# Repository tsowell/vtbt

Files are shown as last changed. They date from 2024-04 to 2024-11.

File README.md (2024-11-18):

# Bluetooth to LK201 bridge for DEC video terminals

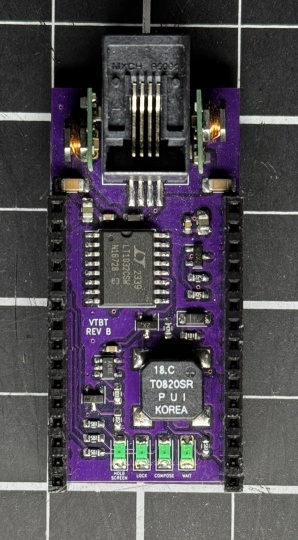
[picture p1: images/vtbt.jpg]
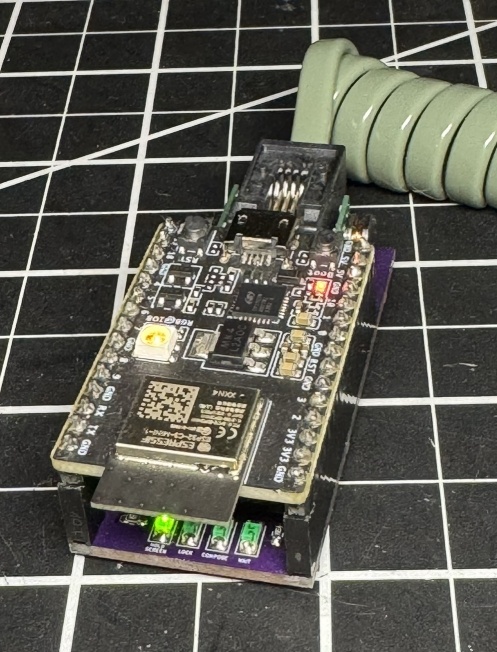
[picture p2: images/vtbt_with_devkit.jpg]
 

This repository contains Zephyr RTOS firmware code and KiCad hardware files for
a device which interfaces a DEC VT to a Bluetooth keyboard via an emulated
LK201 interface.

The vtbt board has a socket for an ESP32-C3-DevKitM-1 which provides the
microcontroller and Bluetooth functionality (as well as 3.3V regulation). The
vtbt provides power from the keyboard interface's 12V supply, performs RS-423
level conversion for the serial interface and has the four LEDs and magnetic
buzzer found in a real LK201 because Bluetooth keyboards are unlikely to have
those.

I built this after I spent great effort to obtain a VT420 but then neglected to
use it due to frustrations with the infamous LK401 keyboard. Once I got the
vtbt capable of "self-hosting", I used it with my VT420 to finish developing
the firmware over a serial console. I found that the terminal actually provides
a very enjoyable and relaxing experience with a decent keyboard!

## What works

Everything documented in the VCB02 Video Subsystem Technical manual is
implemented including:

* Beeps, keyclicks, beep and keyclick volumes
* The four LK201 LED indicators
* Per-key-division auto-repeat, up-down, down-only modes
* All mode-setting operations for changing modes and auto-repeat timings

## What doesn't work

I've only tested the vtbt with DEC VT420 terminals.

The key mapping is set up for the VT420's default "<> Key Sends `~" and "`~ Key
Sends ESC" settings. It may need adjustment for other terminals or
configurations.

Similarly, Alt keys, which are disabled by default on the VT420, are not
supported, but support could be added.

Compose keys have not been tested.

## Usage

1. Build and flash the firmware to an ESP32-C3-DevKitM-1 connected over USB.

   From a Zephyr environment:

   ```west flash```

2. Mount the ESP32-C3-DevKitM-1 on the vtbt with the USB port facing the vtbt's
   modular connector and the ESP32-C3 and antenna on the side with the LEDs.

3. Connect the vtbt to a DEC terminal with a rollover-wired 4P4C module cable
   (like a phone handset cable).

4. Turn on the DEC terminal. The vtbt will display the terminal's power-up
   self-test sequence on its four LEDs followed by a beep.

5. Connect to a Bluetooth keyboard.

   The firmware indicates Bluetooth status via the ESP32-C3-DevKitM-1's RGB
   LED.
  
   Blue means it is searching for a Bluetooth keyboard.
  
   Green means it has found a keyboard and is awaiting authorization. To
   authorize, type 123456<Enter> on the keyboard.
  
   Orange means it is connected to a keyboard and processing keyboard events.
  
   The firmware stores bonded devices and automatically reconnects to them.

## Development

The vtbt's modular connector blocks the ESP32-C3-DevKitM-1's USB port, but for
quicker iterations a pair of pin headers as spacers will make it taller.

vtemu.py in this repository can be used as a basic emulation of a DEC terminal
for testing.

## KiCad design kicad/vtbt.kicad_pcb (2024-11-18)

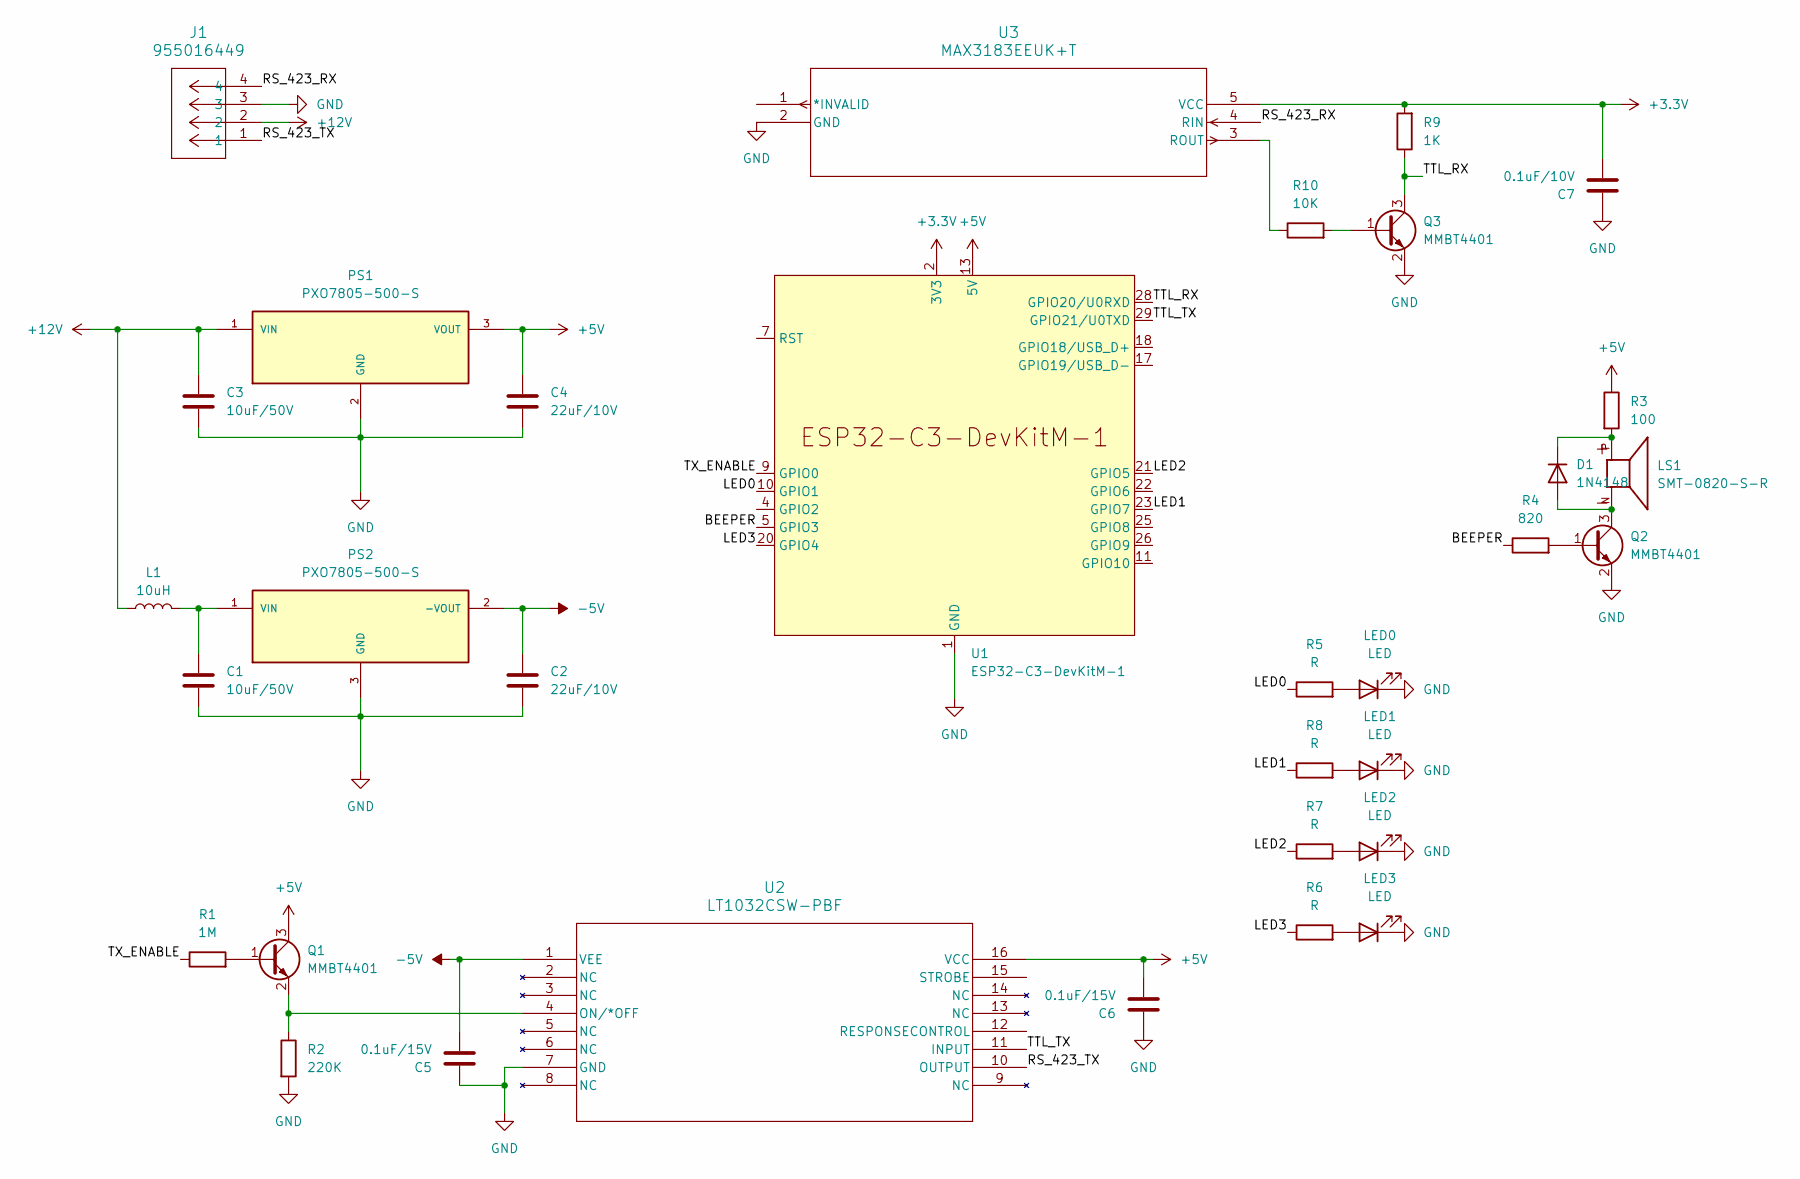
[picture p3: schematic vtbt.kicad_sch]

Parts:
C1, C3: 10uF/50V; C_1206_3216Metric_Pad1.33x1.80mm_HandSolder
C2, C4: 22uF/10V; C_0805_2012Metric_Pad1.18x1.45mm_HandSolder
C5, C6: 0.1uF/15V; C_0603_1608Metric
C7: 0.1uF/10V; C_0603_1608Metric
D1: 1N4148; D_SOD-123
J1: 955016449; CONN_95501-6449_MOL
L1: 10uH; L_0603_1608Metric_Pad1.05x0.95mm_HandSolder
LED0, LED1, LED2, LED3: LED; LED_1206_3216Metric_Pad1.42x1.75mm_HandSolder
LS1: SMT-0820-S-R; XDCR_SMT-0820-S-R; PARTREV B
PS1, PS2: PXO7805-500-S; CONV_PXO7805-500-S; PARTREV 08/22/2022
Q1, Q2, Q3: MMBT4401; SOT-23
R1: 1M; R_0603_1608Metric_Pad0.98x0.95mm_HandSolder
R2: 220K; R_0603_1608Metric_Pad0.98x0.95mm_HandSolder
R3: 100; R_0603_1608Metric_Pad0.98x0.95mm_HandSolder
R4: 820; R_0603_1608Metric_Pad0.98x0.95mm_HandSolder
R5, R6, R7, R8: R; R_0603_1608Metric_Pad0.98x0.95mm_HandSolder
R9: 1K; R_0603_1608Metric_Pad0.98x0.95mm_HandSolder
R10: 10K; R_0603_1608Metric_Pad0.98x0.95mm_HandSolder
U1: ESP32-C3-DevKitM-1; ESP32-C3-DevKitM-1_minimal
U2: LT1032CSW-PBF; SOIC-16W_7.5x10.3mm_P1.27mm
U3: MAX3183EEUK+T; SOT-23-5

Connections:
+3.3V: C7.2, R9.2, U1.2 (3V3), U1.3 (3V3), U3.5 (VCC)
+5V: C4.1, C6.2, PS1.3 (VOUT), Q1.3 (C), R3.1, U1.13 (5V), U1.14 (5V), U2.16 (VCC)
+12V: C3.1, J1.2, L1.1, PS1.1 (VIN)
-5V: C2.1, C5.2, PS2.2 (-VOUT), U2.1 (VEE)
/BEEPER: R4.1, U1.5 (GPIO3)
/LED0: R5.1, U1.10 (GPIO1)
/LED1: R8.1, U1.23 (GPIO7)
/LED2: R7.1, U1.21 (GPIO5)
/LED3: R6.1, U1.20 (GPIO4)
/RS_423_RX: J1.4, U3.4 (RIN)
/RS_423_TX: J1.1, U2.10 (OUTPUT)
/TTL_RX: Q3.3 (C), R9.1, U1.28 (GPIO20/U0RXD)
/TTL_TX: U1.29 (GPIO21/U0TXD), U2.11 (INPUT)
/TX_ENABLE: R1.1, U1.9 (GPIO0)
GND: C1.2, C2.2, C3.2, C4.2, C5.1, C6.1, C7.1, J1.3, LED0.1 (K), LED1.1 (K), LED2.1 (K), LED3.1 (K), PS1.2 (GND), PS2.3 (GND), Q2.2 (E), Q3.2 (E), R2.2, U1.1 (GND), U1.6 (GND), U1.8 (GND), U1.12 (GND), U1.15 (GND), U1.16 (GND), U1.19 (GND), U1.24 (GND), U1.27 (GND), U1.30 (GND), U2.7 (GND), U3.2 (GND)
unnamed: D1.2 (A), LS1.N, Q2.3 (C)
unnamed: D1.1 (K), LS1.P, R3.2
unnamed: LED0.2 (A), R5.2
unnamed: LED1.2 (A), R8.2
unnamed: LED2.2 (A), R7.2
unnamed: LED3.2 (A), R6.2
unnamed: C1.1, L1.2, PS2.1 (VIN)
unnamed: Q1.1 (B), R1.2
unnamed: Q1.2 (E), R2.1, U2.4 (ON/*OFF)
unnamed: Q2.1 (B), R4.2
unnamed: Q3.1 (B), R10.2
unnamed: R10.1, U3.3 (ROUT)

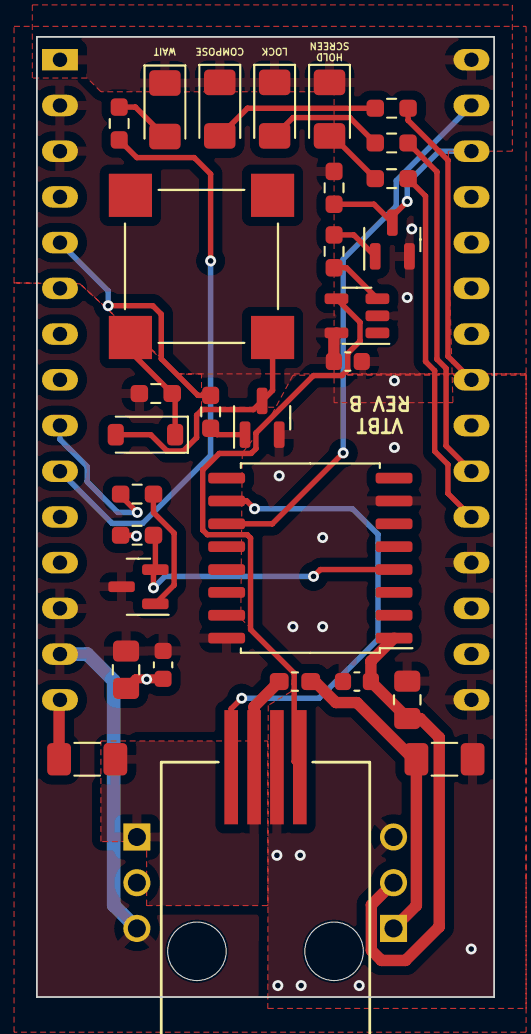
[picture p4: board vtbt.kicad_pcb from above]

Board: 2 copper layers, 25.4 x 53.3 mm, 33 parts (0 on the bottom side), 27 nets.

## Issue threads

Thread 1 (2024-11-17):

Thanks for doing this

TheWanderer1983, 2024-11-17:
I have a Dec VT420 and I'm wanting to use it with a mechanical keyboard. You have saved me a lot of time.

Regards
Dylan

TheWanderer1983, 2024-11-18:
Btw, i have a vt220 also. Did you want me to test with that?

tsowell, 2024-11-19:
That's great to hear. I've been using mine a lot lately and am super happy with it. I'd love to know how it turns out for you.

By the way, I just committed the changes for revision B of the board. The major change is that it uses rollover wiring for the modular connector, so you can use a standard phone headset cable to connect it to the terminal.

TheWanderer1983, 2024-11-24:
Any chance you could put out a gerber and bom? my kicad is stuck at an older version than the one you used.

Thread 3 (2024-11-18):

Support for USBHost

TheWanderer1983, 2024-11-18:
Hello again,

I noticed that you are using the ESP32-C3-DevKitM-1. It has support for the usbhost. See an example https://hackaday.com/2024/11/17/esp32-hosts-a-usb-keyboard-in-this-typewriter/
and
https://github.com/tanakamasayuki/EspUsbHost

Any chance you could incorporate that into this unit. Therefore being able to use a wired usb keyboard not just bluetooth.

Regards
Dylan

tsowell, 2024-11-19:
I agree that would be nice - most of my keyboards are wired, after all. I may get it to it some day, but for now I don't have a specific need for it.

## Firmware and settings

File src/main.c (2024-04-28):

#include <string.h>

#include <zephyr/kernel.h>
#include <zephyr/drivers/gpio.h>
#include <zephyr/drivers/uart.h>
#include <zephyr/logging/log.h>
#include <zephyr/drivers/pwm.h>
#include <zephyr/sys/dlist.h>

#include "vtbt.h"
#include "lk201.h"
#include "beeper.h"
#include "bluetooth.h"
#include "leds.h"
#include "metronome.h"
#include "uart.h"
#include "keyboard.h"

LOG_MODULE_REGISTER(vtbt, CONFIG_LOG_DEFAULT_LEVEL);

static bool test_mode = false;

static sys_dlist_t keys_down;

K_MSGQ_DEFINE(msgq, sizeof(struct event), 32, 4);

static struct event metronome_evt = { EVT_METRONOME, 0 , { 0 } };

static void
metronome(struct k_timer *timer_id)
{
	ARG_UNUSED(timer_id);

	k_msgq_put(&msgq, &metronome_evt, K_NO_WAIT);
}

K_TIMER_DEFINE(metronome_timer, metronome, NULL);

static struct event hid_evt = { EVT_KEYBOARD, HID_REPORT_SIZE, { 0 } };

static void
hid_report_cb(const uint8_t *hid_report)
{
	memcpy(hid_evt.buf, hid_report, HID_REPORT_SIZE);
	k_msgq_put(&msgq, &hid_evt, K_NO_WAIT);
}

static void
send_power_on_test_result(void) {
	const unsigned char test_result[] = {
		SPECIAL_KEYBOARD_ID_FIRMWARE,
		SPECIAL_KEYBOARD_ID_HARDWARE,
		0x00, /* ERROR */
		0x00, /* KEYCODE */
	};
	uart_write(test_result, sizeof(test_result));
}

static struct event callback_evt = { EVT_HOST, 0 , { 0 } };

static void
uart_callback(uint8_t c)
{
	if (c & 0x80) {
		/* no more parameters */
		callback_evt.buf[callback_evt.size++] = c;
		k_msgq_put(&msgq, &callback_evt, K_NO_WAIT);
		callback_evt.size = 0;
	} else if (callback_evt.size < 3) {
		callback_evt.buf[callback_evt.size++] = c;
	}
}

static void
init_defaults(void)
{
	test_mode = false;
	lk201_init_defaults();
	keyboard_init_defaults();
	beeper_set_keyclick_volume(2);
	beeper_set_bell_volume(2);
}

/* FLOW CONTROL */

static void
inhibit_keyboard_transmission(const struct event *event)
{
	ARG_UNUSED(event);

	leds_on(LED_LOCK);

	uart_write_byte(SPECIAL_KBD_LOCKED_ACK);
	uart_flush();
	uart_lock();
}

#define SYS_DLIST_PEEK_TAIL_CONTAINER(__dl, __cn, __n) \
	SYS_DLIST_CONTAINER(sys_dlist_peek_tail(__dl), __cn, __n)

#define SYS_DLIST_PEEK_PREV_CONTAINER(__dl, __cn, __n) \
	((__cn != NULL) ? \
	 SYS_DLIST_CONTAINER(sys_dlist_peek_prev(__dl, &(__cn->__n)),   \
	                              __cn, __n) : NULL)

#define SYS_DLIST_FOR_EACH_CONTAINER_REVERSE(__dl, __cn, __n)           \
	for (__cn = SYS_DLIST_PEEK_TAIL_CONTAINER(__dl, __cn, __n);     \
	     __cn != NULL;                                              \
	     __cn = SYS_DLIST_PEEK_PREV_CONTAINER(__dl, __cn, __n))

static void
resume_keyboard_transmission(const struct event *event)
{
	ARG_UNUSED(event);

	leds_off(LED_LOCK);

	uart_unlock();
	if (uart_overflow_get()) {
		uart_write_byte(SPECIAL_OUTPUT_ERROR);
	}

	/* Send unsent key down in reverse order */
	struct key_down *cn;
	SYS_DLIST_FOR_EACH_CONTAINER_REVERSE(&keys_down, cn, node) {
		if (cn->sent) {
			continue;
		}

		uart_write_byte(cn->keycode);
		cn->sent = true;
	}

	metronome_resend();
}

/* INDICATORS */

static void
light_leds(const struct event *event)
{
	if (event->size != 2) {
		uart_write_byte(SPECIAL_INPUT_ERROR);
		metronome_resend();
		return;
	}

	for (int i = 0; i < 4; i++) {
		if (event->buf[1] & (1 << i)) {
			leds_on(i);
		}
	}
}

static void
turn_off_leds(const struct event *event)
{
	if (event->size != 2) {
		uart_write_byte(SPECIAL_INPUT_ERROR);
		metronome_resend();
		return;
	}

	for (int i = 0; i < 4; i++) {
		if (event->buf[1] & (1 << i)) {
			leds_off(i);
		}
	}
}

/* AUDIO */

static void
disable_keyclick(const struct event *event)
{
	ARG_UNUSED(event);

	beeper_set_keyclick_volume(-1);
}

static void
enable_keyclick_set_volume(const struct event *event)
{
	if (event->size != 2) {
		uart_write_byte(SPECIAL_INPUT_ERROR);
		metronome_resend();
		return;
	}

	beeper_set_keyclick_volume(event->buf[1] & 0x07);
}

static void
disable_ctrl_keyclick(const struct event *event)
{
	ARG_UNUSED(event);

	keyboard_ctrl_keyclick_disable();
}

static void
enable_ctrl_keyclick(const struct event *event)
{
	ARG_UNUSED(event);

	keyboard_ctrl_keyclick_enable();
}

static void
sound_keyclick(const struct event *event)
{
	ARG_UNUSED(event);

	beeper_sound_keyclick();
}

static void
disable_bell(const struct event *event)
{
	ARG_UNUSED(event);

	beeper_set_bell_volume(-1);
}

static void
enable_bell_set_volume(const struct event *event)
{
	if (event->size != 2) {
		uart_write_byte(SPECIAL_INPUT_ERROR);
		metronome_resend();
		return;
	}

	beeper_set_bell_volume(event->buf[1] & 0x07);
}

static void
sound_bell(const struct event *event)
{
	ARG_UNUSED(event);

	beeper_sound_bell();
}

/* AUTO-REPEAT */

static void
temporary_auto_repeat_inhibit(const struct event *event)
{
	ARG_UNUSED(event);

	struct key_down *cn;
	SYS_DLIST_FOR_EACH_CONTAINER(&keys_down, cn, node) {
		struct division *division =
			lk201_division_get_from_keycode(cn->keycode);
		if (division == NULL) {
			continue;
		} else if (cn->inhibit_auto_repeat == true) {
			continue;
		} else if (division->mode == MODE_AUTO_REPEAT) {
			cn->inhibit_auto_repeat = true;
			break;
		}
	}
}

static void
enable_auto_repeat_across_keyboard(const struct event *event)
{
	ARG_UNUSED(event);

	metronome_auto_repeat_enable();
}

static void
disable_auto_repeat_across_keyboard(const struct event *event)
{
	ARG_UNUSED(event);

	metronome_auto_repeat_disable();
}

static void
change_all_auto_repeat_to_down_only(const struct event *event)
{
	ARG_UNUSED(event);

	lk201_change_all_auto_repeat_to_down_only();
}

/* OTHER */

static void
request_keyboard_id(const struct event *event)
{
	ARG_UNUSED(event);

	const unsigned char keyboard_id[] = {
		SPECIAL_KEYBOARD_ID_FIRMWARE,
		SPECIAL_KEYBOARD_ID_HARDWARE,
	};
	uart_write(keyboard_id, sizeof(keyboard_id));
}

static void
jump_to_power_up(const struct event *event)
{
	ARG_UNUSED(event);

	init_defaults();
	send_power_on_test_result();
}

static void
jump_to_test_mode(const struct event *event)
{
	ARG_UNUSED(event);

	test_mode = true;

	uart_write_byte(SPECIAL_TEST_MODE_ACK);
}

static void
reinstate_defaults(const struct event *event)
{
	ARG_UNUSED(event);

	init_defaults();
}

static void
test_mode_jump_to_power_up(const struct event *event)
{
	ARG_UNUSED(event);

	init_defaults();
	send_power_on_test_result();
}

static void
peripheral_command(const struct event *event)
{
	switch (event->buf[0]) {
		/* FLOW CONTROL */
		case COMMAND_RESUME_KEYBOARD_TRANSMISSION:
			resume_keyboard_transmission(event);
			break;
		case COMMAND_INHIBIT_KEYBOARD_TRANSMISSION:
			inhibit_keyboard_transmission(event);
			break;
		/* INDICATORS */
		case COMMAND_TURN_OFF_LEDS:
			turn_off_leds(event);
			break;
		case COMMAND_LIGHT_LEDS:
			light_leds(event);
			break;
		/* AUDIO */
		case COMMAND_DISABLE_KEYCLICK:
			disable_keyclick(event);
			break;
		case COMMAND_ENABLE_KEYCLICK_SET_VOLUME:
			enable_keyclick_set_volume(event);
			break;
		case COMMAND_DISABLE_CTRL_KEYCLICK:
			disable_ctrl_keyclick(event);
			break;
		case COMMAND_ENABLE_CTRL_KEYCLICK:
			enable_ctrl_keyclick(event);
			break;
		case COMMAND_SOUND_KEYCLICK:
			sound_keyclick(event);
			break;
		case COMMAND_DISABLE_BELL:
			disable_bell(event);
			break;
		case COMMAND_ENABLE_BELL_SET_VOLUME:
			enable_bell_set_volume(event);
			break;
		case COMMAND_SOUND_BELL:
			sound_bell(event);
			break;
		/* AUTO-REPEAT */
		case COMMAND_TEMPORARY_AUTO_REPEAT_INHIBIT:
			temporary_auto_repeat_inhibit(event);
			break;
		case COMMAND_ENABLE_AUTO_REPEAT_ACROSS_KEYBOARD:
			enable_auto_repeat_across_keyboard(event);
			break;
		case COMMAND_DISABLE_AUTO_REPEAT_ACROSS_KEYBOARD:
			disable_auto_repeat_across_keyboard(event);
			break;
		case COMMAND_CHANGE_ALL_AUTO_REPEAT_TO_DOWN_ONLY:
			change_all_auto_repeat_to_down_only(event);
			break;
		/* OTHER */
		case COMMAND_REQUEST_KEYBOARD_ID:
			request_keyboard_id(event);
			break;
		case COMMAND_JUMP_TO_POWER_UP:
			jump_to_power_up(event);
			break;
		case COMMAND_JUMP_TO_TEST_MODE:
			jump_to_test_mode(event);
			break;
		case COMMAND_REINSTATE_DEFAULTS:
			reinstate_defaults(event);
			break;
		default:
			uart_write_byte(SPECIAL_INPUT_ERROR);
			break;
	}
}

static void
transmission_command(const struct event *event)
{
	int division = (event->buf[0] >> 3) & 0x0f;
	if (division == 0x0f) {
		if (event->size != 3) {
			uart_write_byte(SPECIAL_INPUT_ERROR);
			metronome_resend();
			return;
		}
		int buffer = (event->buf[0] >> 1) & 0x03;
		int timeout = ((event->buf[1]) & 0x7f) * 5;
		int interval = 1000 / ((event->buf[2]) & 0x7f);
		lk201_repeat_buffer_get(buffer)->timeout = timeout;
		lk201_repeat_buffer_get(buffer)->interval = interval;
	} else if (division == 0x00) {
		uart_write_byte(SPECIAL_INPUT_ERROR);
		metronome_resend();
		return;
	} else {
		int mode = ((event->buf[0]) >> 1) & 0x03;
		lk201_division_get(division-1)->mode = mode;
		if (mode == MODE_AUTO_REPEAT) {
			if (event->size == 2) {
				int buffer = event->buf[1] & 0x7f;
				lk201_division_get(division-1)->buffer = buffer;
			} else {
				/* Default buffer? */
				lk201_division_get(division-1)->buffer = 0;
			}
		}

		uart_write_byte(SPECIAL_MODE_CHANGE_ACK);
		metronome_resend();
	}
}

static void
host_event(const struct event *event)
{
	if (event->size == 0) {
		return;
	}

	if (test_mode) {
		if (event->buf[0] == TEST_MODE_COMMAND_JUMP_TO_POWER_UP) {
			test_mode_jump_to_power_up(event);
		}
	} else {
		if (event->buf[0] & 0x01) {
			peripheral_command(event);
		} else {
			transmission_command(event);
		}
	}
}

static void
handle_events(void)
{
	struct event event;

	while (k_msgq_get(&msgq, &event, K_FOREVER) == 0) {
		switch (event.source) {
			case EVT_HOST:
				host_event(&event);
				break;
			case EVT_METRONOME:
				metronome_event(&keys_down, &event);
				break;
			case EVT_KEYBOARD:
				keyboard_event(&keys_down, &event);
				break;
			default:
				break;
		}
	}
}

int
main(void)
{
	int ret;

	sys_dlist_init(&keys_down);

	init_defaults();

	leds_init();
	beeper_init();

	for (int i = 0; i < NUM_REPEAT_BUFFERS; i++) {
		lk201_repeat_buffer_get(i)->timeout = 300;
		lk201_repeat_buffer_get(i)->interval = 30;
	}

	ret = uart_init();
	if (ret < 0) {
		LOG_ERR("UART init failed: %d", ret);
		return -1;
	}

	ret = uart_set_rx_callback(uart_callback);
	if (ret < 0) {
		LOG_ERR("UART set rx callback failed: %d", ret);
		return -1;
	}

	send_power_on_test_result();
	uart_write_byte(SPECIAL_INPUT_ERROR);
	uart_write_byte(SPECIAL_MODE_CHANGE_ACK);

	k_timer_start(&metronome_timer, K_MSEC(1), K_MSEC(1));

	ret = bluetooth_listen(hid_report_cb);
	if (ret < 0) {
		LOG_ERR("Bluetooth listening failed");
		return -1;
	}

	handle_events();
}

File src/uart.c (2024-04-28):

#include <zephyr/kernel.h>
#include <zephyr/drivers/gpio.h>
#include <zephyr/drivers/uart.h>
#include <zephyr/logging/log.h>
#include <zephyr/sys/ring_buffer.h>

#include "uart.h"

LOG_MODULE_REGISTER(uart, CONFIG_LOG_DEFAULT_LEVEL);

#define UART_DEVICE_NODE DT_CHOSEN(zephyr_vt_uart)

/* 4-byte TX buffer, just like on the LK201. */
RING_BUF_DECLARE(tx_buf, 4);

/* Given by TX callback when new space is available in the TX buffer. */
K_SEM_DEFINE(tx_space_sem, 0, 1);

static const struct device *const uart_dev = DEVICE_DT_GET(UART_DEVICE_NODE);

/* Enable the RS-423 driver. It is disabled by default in order to prevent
 * transmission of bootloader, etc. output from the devkit. */
static const struct gpio_dt_spec uart_tx_enable =
	GPIO_DT_SPEC_GET_OR(DT_NODELABEL(uart_tx_enable), gpios, {0});

static serial_cb user_callback = NULL;

static atomic_t locked;
static bool overflow;

static void
callback_tx(void)
{
	uint32_t size;
	int filled_size;
	uint8_t *data;

	if (atomic_get(&locked)) {
		uart_irq_tx_disable(uart_dev);
		return;
	}

	while (!ring_buf_is_empty(&tx_buf)) {
		size = ring_buf_get_claim(&tx_buf, &data, 4);
		filled_size = uart_fifo_fill(uart_dev, data, size);
		if (filled_size < 0) {
			ring_buf_get_finish(&tx_buf, 0);
			return;
		}
		int ret = ring_buf_get_finish(&tx_buf, (uint32_t)filled_size);
		if (filled_size > 0) {
			k_sem_give(&tx_space_sem);
		}
		if (ret < 0) {
			return;
		}
	}

	uart_irq_tx_disable(uart_dev);
}

static void
callback_rx(void)
{
	uint8_t c;

	/* read until FIFO empty */
	while (uart_fifo_read(uart_dev, &c, 1) == 1) {
		if (user_callback) {
			user_callback(c);
		}
	}
}


static void
callback(const struct device *dev, void *user_data)
{
	ARG_UNUSED(dev);
	ARG_UNUSED(user_data);

	if (uart_irq_update(uart_dev) < 0) {
		return;
	}

	if (uart_irq_tx_ready(uart_dev) > 0) {
		callback_tx();
	}

	if (uart_irq_rx_ready(uart_dev) > 0) {
		callback_rx();
	}
}

int
uart_init(void)
{
	int ret;

	if (!device_is_ready(uart_dev)) {
		LOG_ERR("UART device not found");
		return -1;
	}

	if (!gpio_is_ready_dt(&uart_tx_enable)) {
		LOG_ERR("UART TX enable pin GPIO port is not ready.");
		return -1;
	}

	ret = gpio_pin_configure_dt(&uart_tx_enable, GPIO_OUTPUT_ACTIVE);
	if (ret != 0) {
		LOG_ERR("Configuring GPIO pin failed: %d", ret);
		return -1;
	}

	return 0;
}

int
uart_set_rx_callback(serial_cb serial_cb)
{
	int ret;

	user_callback = serial_cb;

	ret = uart_irq_callback_user_data_set(uart_dev, callback, NULL);
	if (ret < 0) {
		if (ret == -ENOTSUP) {
			LOG_ERR("Interrupt-driven UART not enabled");
		} else if (ret == -ENOSYS) {
			LOG_ERR("UART does not support interrupt-driven API");
		} else {
			LOG_ERR("Error setting UART callback: %d", ret);
		}
		return -1;
	}
	uart_irq_rx_enable(uart_dev);
	return 0;
}

int
uart_write_byte(unsigned char out_char)
{
	while (ring_buf_put(&tx_buf, &out_char, 1) < 1) {
		if (atomic_get(&locked)) {
			overflow = true;
			return 0;
		}
		k_sem_take(&tx_space_sem, K_FOREVER);
	}
	uart_irq_tx_enable(uart_dev);
	return 1;
}

int
uart_write(const unsigned char buf[], size_t count)
{
	uint32_t total = 0;
	while (true) {
		uint32_t wrote = ring_buf_put(
			&tx_buf, &buf[total], count - total);
		if (atomic_get(&locked)) {
			if (wrote < count) {
				overflow = true;
			}
			return (int)wrote;
		}
		if (wrote > 0) {
			uart_irq_tx_enable(uart_dev);
		}
		total += wrote;
		if (total >= count) {
			break;
		}
		k_sem_take(&tx_space_sem, K_FOREVER);
	}

	return count;
}

void
uart_flush(void)
{
	uart_irq_tx_enable(uart_dev);
	while (!ring_buf_is_empty(&tx_buf)) {
		k_sem_take(&tx_space_sem, K_FOREVER);
	}
}

void
uart_lock(void)
{
	if (atomic_get(&locked)) {
		return;
	}

	atomic_set(&locked, 1);
	overflow = false;
}

void
uart_unlock(void)
{
	if (!atomic_get(&locked)) {
		return;
	}

	atomic_set(&locked, 0);

	uart_flush();
}

bool
uart_overflow_get(void)
{
	return overflow;
}

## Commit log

2024-04-28 LEDs for pairing status
2024-04-28 Disable saving devices
2024-04-28 LEDs, working on beeper
2024-04-28 Remove UART mutex
2024-04-28 Use final LED GPIOs
2024-04-28 Flow control
2024-04-28 Fix #define case in leds.h
    [leds.h]
2024-04-28 Refactor flow control into module
2024-04-28 Iterate down keys in reverse without temp buffer
    [main.c]
2024-04-28 Use int-driven UART, msgqs for keyboard, timer
2024-04-28 Send input error on unrecognized command
    [main.c]
2024-04-28 Remap `~ to <> and Esc to `~
    This produces the correct corresponding keycodes with the default VT420
    settings which translate <> to `~ and `~ to Esc.
2024-04-28 Clean up formatting
    bluetooth.c was inherited from Zephyr sample code and needed some
    cleanup for consistency.
2024-04-28 Set LED to amber for already-bonded devices
2024-04-28 Fix incorrect constant usage
    [keyboard.c]
2024-04-28 Use on/off API for LEDs for consistency
2024-04-28 Add KiCad project
    [vtbt.kicad_pcb, vtbt.kicad_sch]
2024-04-28 Set board for Zephyr
2024-11-18 Reroute for rollover-wired modular cable
    Phone handset cables are commonly available and use rollover-wiring.
    [vtbt.kicad_pcb, vtbt.kicad_sch]
